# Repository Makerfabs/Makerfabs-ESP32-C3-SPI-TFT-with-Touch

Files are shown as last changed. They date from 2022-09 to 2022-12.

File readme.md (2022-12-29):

# Makerfabs ESP32-C3 SPI TFT with Touch

```c++
/*
Version:		V1.3
Author:			Vincent
Create Date:	2022/9/23
Note:
		2022/10/13	V1.1: Add example
		2022/10/18	V1.2: Add Line Chart demo
		2022/12/29	V1.3: Change wiki link
*/
```
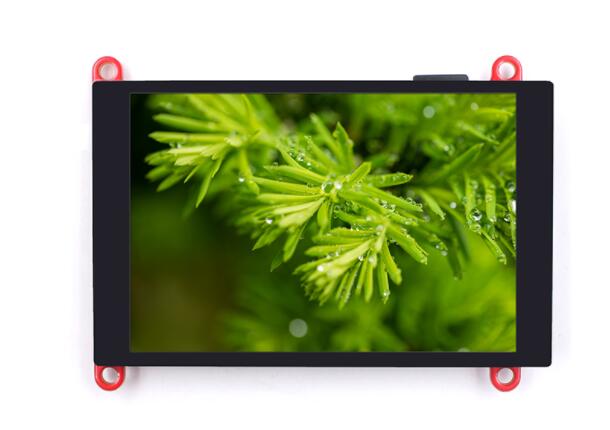
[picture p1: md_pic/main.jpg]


[toc]

# Makerfabs

[Makerfabs home page](https://www.makerfabs.com/)

[Makerfabs Wiki](https://wiki.makerfabs.com/)

# Makerfabs ESP32-C3 SPI TFT with Touch
## Intruduce

Product Link ：[ESP32-C3 SPI TFT with Touch 3.5'' ILI9488](https://www.makerfabs.com/ep32-c3-risc-v-spi-tft-touch.html)

Wiki Link : [ESP32-C3_SPI_TFT_with_Touch](https://wiki.makerfabs.com/ESP32_C3_SPI_3.5_TFT_with_Touch.html)

Makerfabs ESP32-C3 TFT Touch equips with ESP32-C3, which is a single-core Wi-Fi and Bluetooth 5 (LE) microcontroller SoC, built around a 32-bit **RISC-V** chip processor with a four-stage pipeline that operates at up to 160 MHz, with 4MB Flash, 400KB SRAM. 

Being a number of the Makerfabs ESP Display family, this ESP32 C3 SPI 3.5 inch Touch is 320*480, with ILI9488 driver. Same as the other Makerfab's ESP32 displays, there 2 USB connectors, one for USB2UART convertor, and 1 USB native; on-board SD card, and Mabee connector(I2C) which is Seeedstudio Grove compatible, so it fits for applications that need sensor connected.

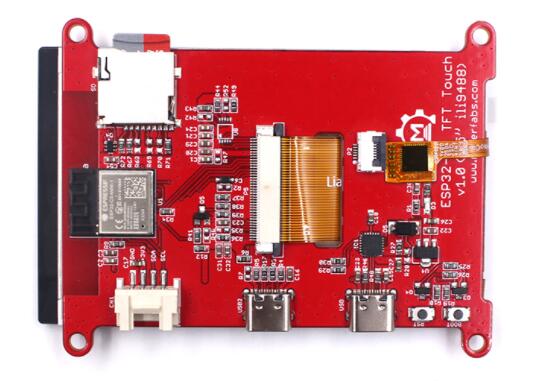
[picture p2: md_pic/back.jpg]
back


## Feature

- Controller: ESP32-C3-MINI-1-N4, 4MB Flash, RISCV-32bit, 160MHz, 400KB SRAM, Bluetooth 5
- Wireless: WiFi & Bluetooth 5.0
- LCD: 3.5inch TFT LCD
- Resolution: 480*320
- Color: RGB
- LCD interface: SPI
- LCD Driver: ili9488
- Touch Panel: Capacitive
- Touch Panel Driver: FT6236
- USB: Dual USB Type-C(one for USB-to-UART and one for native USB)
- USB2UART Chip: CP2104
- Power Supply: USB Type-C 5.0V(4.0V~5.25V)
- Button: Flash button and reset button
- Mabee interface: 1*I2C
- Backlight Controller: Yes
- MicroSD: Yes
- Arduino support: Yes
- Type-C Power Delivery: Not Supported
- Operation temperature: -40℃ to +85℃
- Dimension: 66mm * 84.3mm * 12mm
- Weight: 52g

# Code Explain

## Complier Option

- Install board : ESP32 .
- Install library : LovyanGFX library. 
- Use type-c use cable connect USB-TTL to PC.
- Upload codes, select "ESP32-C3 DEV Module"

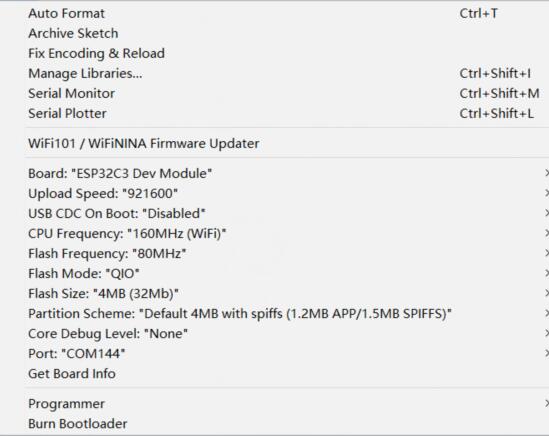
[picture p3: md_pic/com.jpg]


## Firmware

### c3_9488

A simple test procedure. Touch the black area in the middle of the screen, and the screen starts showing solid colors in turn. Finally, an SD card image is displayed.

## Example

### Mabee CO2 Display

SGP30 and SHT31 sensor values are displayed on the screen. Use [Mabee CO2](https://www.makerfabs.com/mabee-tvoc-and-eco2-sgp30-sht31.html) sensor.

Need libraries:

- Adafruit_SGP30
- Adafruit_SHT31

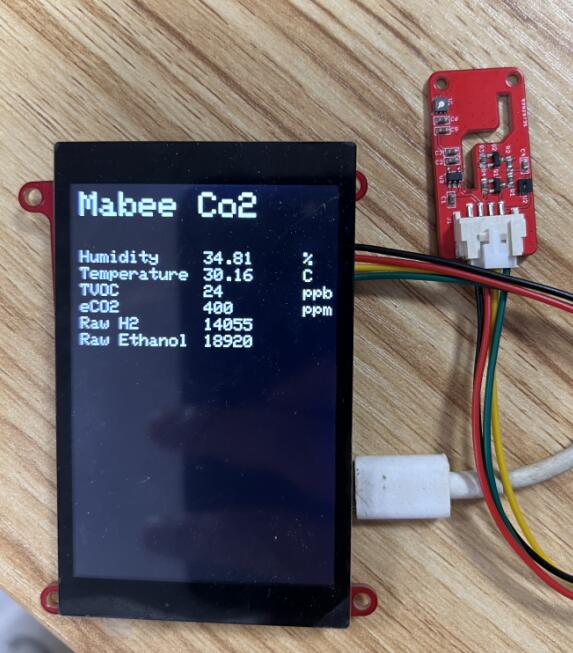
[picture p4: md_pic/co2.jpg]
co2


### TVOC line chart

Shows a line chart of TVOC

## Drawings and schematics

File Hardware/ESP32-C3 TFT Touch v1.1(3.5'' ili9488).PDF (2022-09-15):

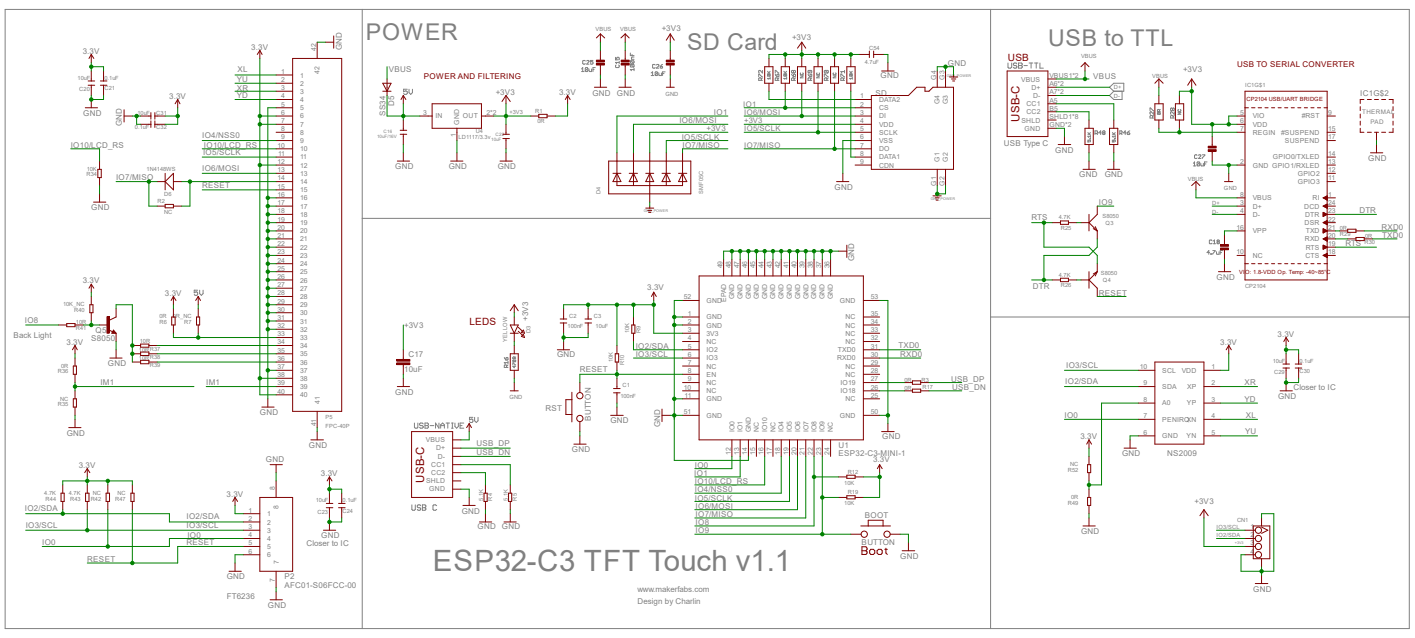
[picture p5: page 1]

USB Type C SD Card

USB TO SERIAL CONVERTER

VIO: 1.8-VDD Op. Temp: -40~85°C USB⁻C USB⁻C

Design by Charlin ESP32-C3 TFT Touch v1.1

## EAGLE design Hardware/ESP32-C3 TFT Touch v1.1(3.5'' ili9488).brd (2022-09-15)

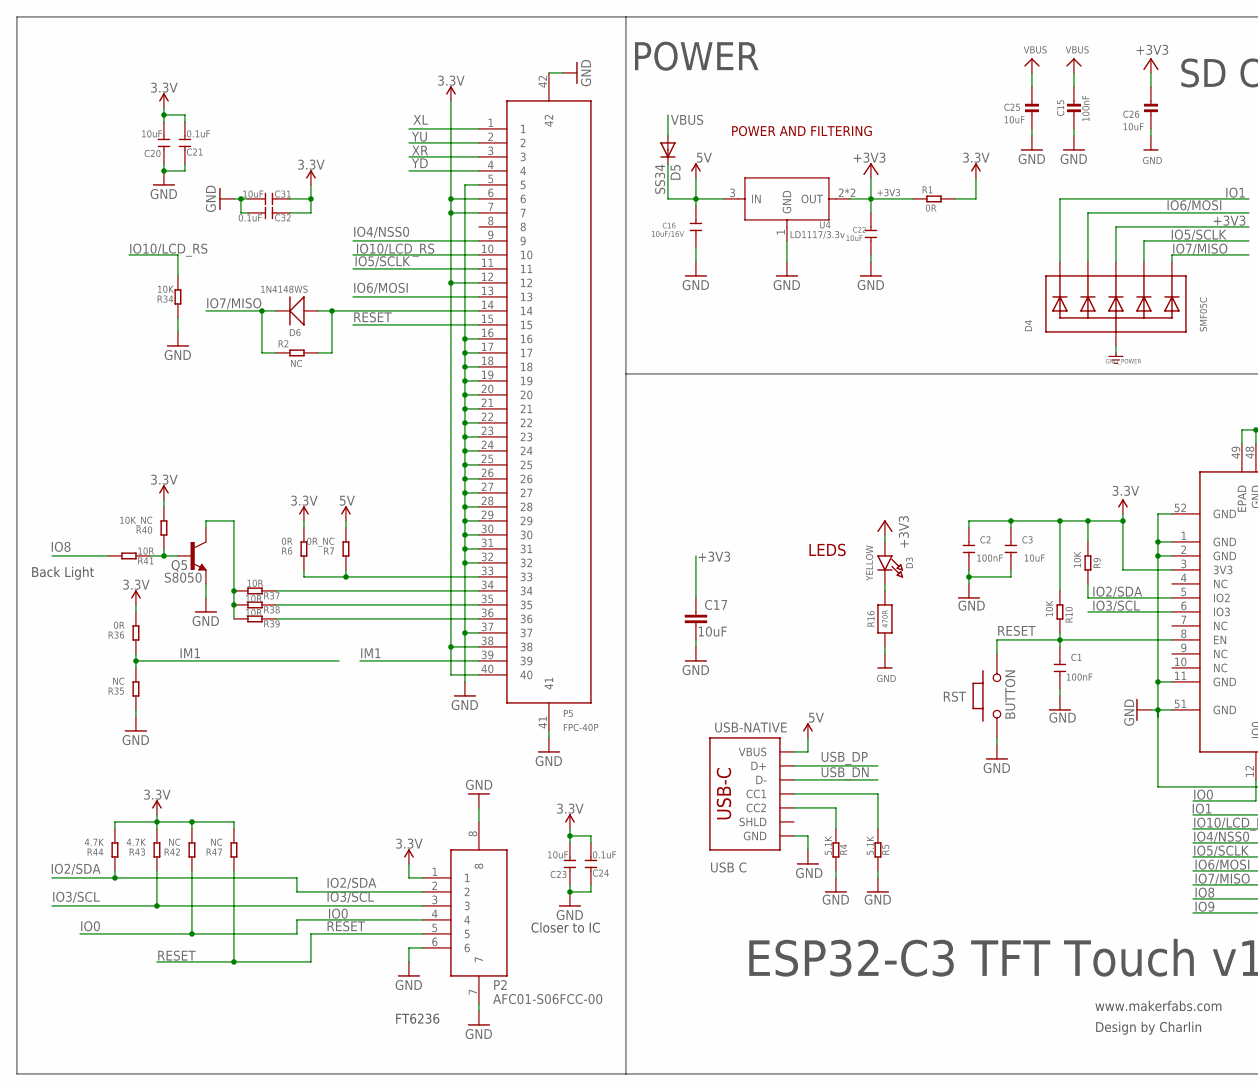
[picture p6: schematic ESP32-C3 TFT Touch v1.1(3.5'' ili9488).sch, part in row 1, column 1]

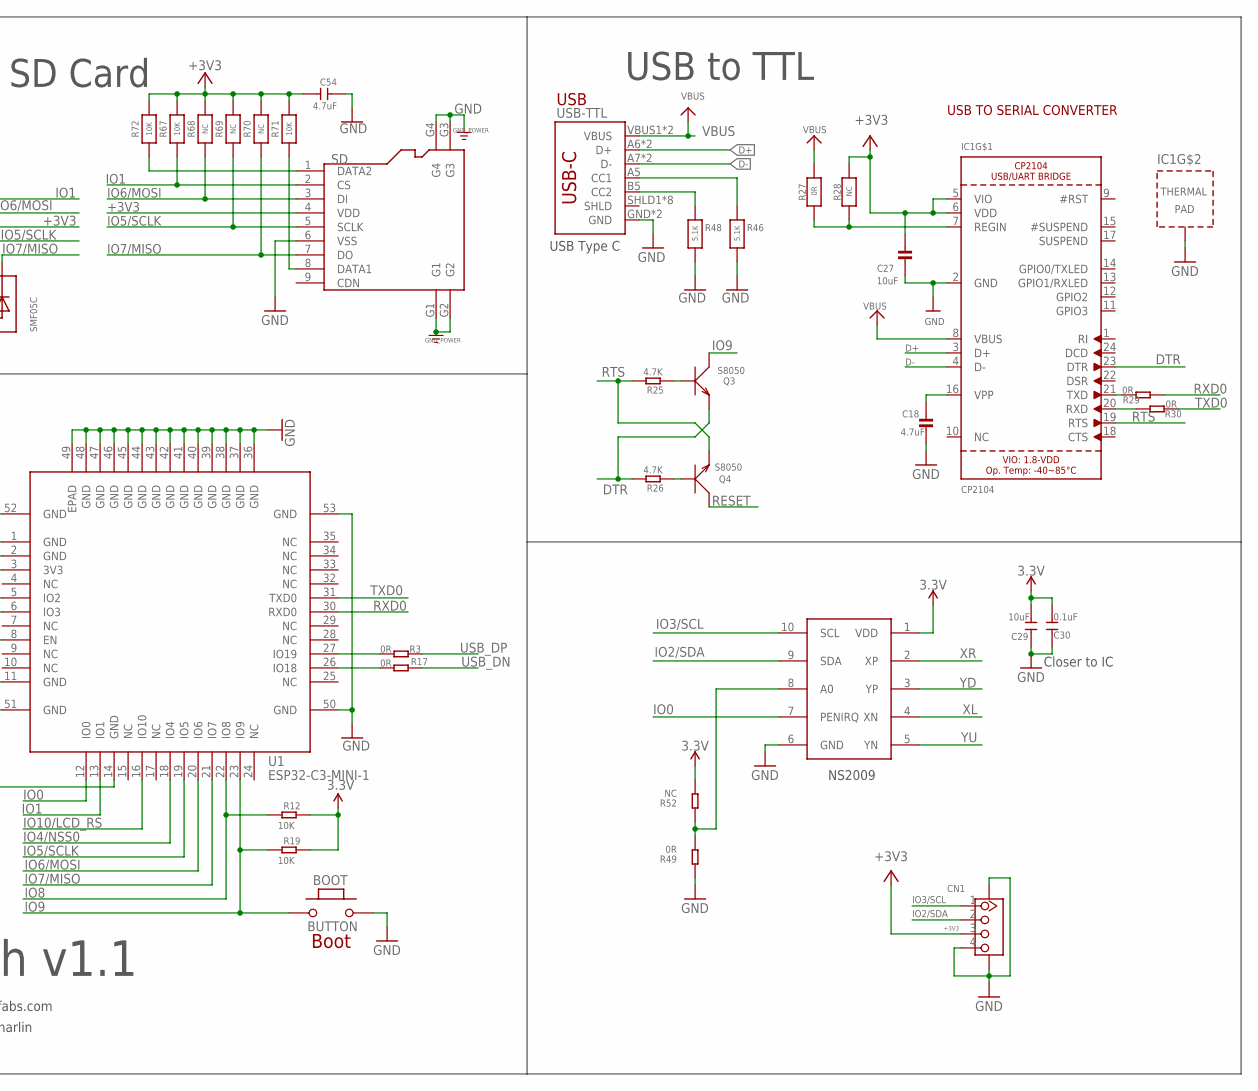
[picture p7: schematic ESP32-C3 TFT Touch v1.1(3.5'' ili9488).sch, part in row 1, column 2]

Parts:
BOOT: BUTTON; 157SW
C1, C2: 100nF; C0603
C3, C17, C22: 10uF; C0603
C15: 100nF; 0603-NO
C16: 10uF/16V; C0603
C18: 4.7uF; 0603-NO
C20, C23, C29, C31: 10uF; DISCRETE_C0603
C21, C24, C30, C32: 0.1uF; DISCRETE_C0603
C25, C26, C27: 10uF; 0603-NO
C54: 4.7uF; DISCRETE_C0603
CN1: GROVE-CONNECTOR-SMD'90D'; HW4-SMD-2.0-90D
D3: YELLOW; CHIPLED_0805_NOOUTLINE
D4: SMF05C; SOT363
D5: SS34; DO-214AC
D6: 1N4148WS; SOD323
IC1: CP2104; QFN24_4MM_SMSC
P2: AFC01-S06FCC-00; SMD8-50P-740L535W
P5: FPC-40P; SMD42-50P-2560L490W
Q3, Q4: S8050; SOT23
Q5: S8050; SPARKFUN_SOT23
R1, R3, R17, R29, R30: 0R; R0603
R2: NC; R0603
R4, R5: 5.1K; R0603
R6, R36, R49: 0R; DISCRETE_R0603
R7: 0R_NC; DISCRETE_R0603
R9, R10, R12, R19: 10K; R0603
R16: 470R; 0603-NO
R25, R26: 4.7K; R0603
R27: 0R; 0603-NO
R28, R68, R69, R70: NC; 0603-NO
R34: 10K; DISCRETE_R0603
R35, R42, R47, R52: NC; DISCRETE_R0603
R37, R38, R39, R41: 10R; DISCRETE_R0603
R40: 10K_NC; DISCRETE_R0603
R43, R44: 4.7K; DISCRETE_R0603
R46, R48: 5.1K; 0603-NO
R67, R71, R72: 10K; 0603-NO
RST: BUTTON; 157SW
SD: HOLDER-MICROSD-9P; 9P-SMD-W/-RING
U1: ESP32-C3-MINI-1
U4: LD1117/3.3v; SOT89
U8: NS2009; MSOP10
USB-NATIVE: USB C; USB-C-16P-4LAYER-ISOLATED
USB-TTL: USB_C5; USB-C-16P-5

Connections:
3.3V: C2.2, C3.2, C20.2, C21.2, C23.2, C24.2, C29.2, C30.2, C31.1, C32.1, P2.1, P5.6, P5.7, P5.12, P5.38, P5.40, R1.2, R6.2, R9.1, R10.1, R12.2, R19.2, R36.2, R40.2, R42.2, R43.2, R44.2, R47.2, R52.2, U1.3 (3V3), U8.1 (VDD)
5V: C16.1, D5.C, R7.2, U4.3 (IN), USB-NATIVE.VBUS1 (VBUS), USB-NATIVE.VBUS2 (VBUS)
+3V3: C17.1, C22.1, C26.1, C27.1, C54.2, CN1.3, D3.A, D4.4 (C3), IC1.5 (VIO), IC1.6 (VDD), R1.1, R28.1, R67.2, R68.2, R69.2, R70.2, R71.2, R72.2, SD.4 (VDD), U4.2 (OUT), U4.4 (OUT)
D+: IC1.3 (D+), USB-TTL.A6 (D+), USB-TTL.B6 (D+)
D-: IC1.4 (D-), USB-TTL.A7 (D-), USB-TTL.B7 (D-)
DTR: IC1.23 (DTR), Q3.2 (E), R26.2
GND: BOOT.2, C1.1, C2.1, C3.1, C15.2, C16.2, C17.2, C18.2, C20.1, C21.1, C22.2, C23.1, C24.1, C25.2, C26.2, C27.2, C29.1, C30.1, C31.2, C32.2, C54.1, CN1.4, CN1.SS1, CN1.SS2, D4.2 (A), IC1.2 (GND), IC1.THERM (TP), P2.6, P2.7, P2.8, P5.5, P5.16, P5.17, P5.18, P5.19, P5.20, P5.21, P5.22, P5.23, P5.24, P5.25, P5.26, P5.27, P5.28, P5.29, P5.30, P5.31, P5.32, P5.37, P5.41, P5.42, Q5.2 (E), R4.1, R5.1, R16.1, R34.1, R35.1, R46.2, R48.2, R49.1, RST.1, SD.6 (VSS), SD.G1, SD.G2, SD.G3, SD.G4, U1.1 (GND), U1.2 (GND), U1.11 (GND), U1.14 (GND), U1.36 (GND), U1.37 (GND), U1.38 (GND), U1.39 (GND), U1.40 (GND), U1.41 (GND), U1.42 (GND), U1.43 (GND), U1.44 (GND), U1.45 (GND), U1.46 (GND), U1.47 (GND), U1.48 (GND), U1.49 (EPAD), U1.50 (GND), U1.51 (GND), U1.52 (GND), U1.53 (GND), U4.1 (GND), U8.6 (GND), USB-NATIVE.GND, USB-NATIVE.GND2 (GND), USB-TTL.GND, USB-TTL.GND2 (GND)
IM1: P5.39, R35.2, R36.1
IO0: P2.4, R42.1, U1.12 (IO0), U8.7 (PENIRQ)
IO1: D4.1 (C1), R67.1, SD.2 (CS), U1.13 (IO1)
IO2/SDA: CN1.2, P2.2, R9.2, R44.1, U1.5 (IO2), U8.9 (SDA)
IO3/SCL: CN1.1, P2.3, R43.1, U1.6 (IO3), U8.10 (SCL)
IO4/NSS0: P5.9, U1.18 (IO4)
IO5/SCLK: D4.5 (C4), P5.11, R69.1, SD.5 (SCLK), U1.19 (IO5)
IO6/MOSI: D4.3 (C2), P5.13, R68.1, SD.3 (DI), U1.20 (IO6)
IO7/MISO: D4.6 (C5), D6.-, R2.1, R70.1, SD.7 (DO), U1.21 (IO7)
IO8: R12.1, R41.2, U1.22 (IO8)
IO9: BOOT.1, Q3.3 (C), R19.1, U1.23 (IO9)
IO10/LCD_RS: P5.10, R34.2, U1.16 (IO10)
unnamed: C18.1, IC1.16 (VPP)
unnamed: Q4.1 (B), R26.1
unnamed: Q3.1 (B), R25.1
unnamed: D6.+, P5.14, R2.2
unnamed: D3.C, R16.2
unnamed: R46.1, USB-TTL.A5 (CC1)
unnamed: R48.1, USB-TTL.B5 (CC2)
unnamed: IC1.7 (REGIN), R27.2, R28.2
unnamed: R3.1, U1.27 (IO19)
unnamed: R5.2, USB-NATIVE.A5 (CC1)
unnamed: R4.2, USB-NATIVE.B5 (CC2)
unnamed: R17.1, U1.26 (IO18)
unnamed: IC1.21 (TXD), R29.2
unnamed: IC1.20 (RXD), R30.2
unnamed: P5.34, R37.1
unnamed: P5.35, R38.1
unnamed: P5.36, R39.1
unnamed: Q5.1 (B), R40.1, R41.1
unnamed: Q5.3 (C), R37.2, R38.2, R39.2
unnamed: R49.2, R52.1, U8.8 (A0)
unnamed: P5.33, R6.1, R7.1
unnamed: R72.1, SD.1 (DATA2)
unnamed: R71.1, SD.8 (DATA1)
RESET: C1.2, P2.5, P5.15, Q4.3 (C), R10.2, R47.1, RST.2, U1.8 (EN)
RTS: IC1.19 (RTS), Q4.2 (E), R25.2
RXD0: R29.1, U1.30 (RXD0)
TXD0: R30.1, U1.31 (TXD0)
USB_DN: R17.2, USB-NATIVE.A7 (D-), USB-NATIVE.B7 (D-)
USB_DP: R3.2, USB-NATIVE.A6 (D+), USB-NATIVE.B6 (D+)
VBUS: C15.1, C25.1, D5.A, IC1.8 (VBUS), R27.1, USB-TTL.VBUS1 (VBUS), USB-TTL.VBUS2 (VBUS)
XL: P5.1, U8.4 (XN)
XR: P5.3, U8.2 (XP)
YD: P5.4, U8.3 (YP)
YU: P5.2, U8.5 (YN)

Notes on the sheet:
www.makerfabs.com
Design by Charlin
USB
LEDS
POWER AND FILTERING
USB TO SERIAL CONVERTER
ESP32-C3 TFT Touch v1.1
POWER
USB to TTL
USB Type C
SD Card
NS2009
FT6236
Closer to IC
Back Light
Boot

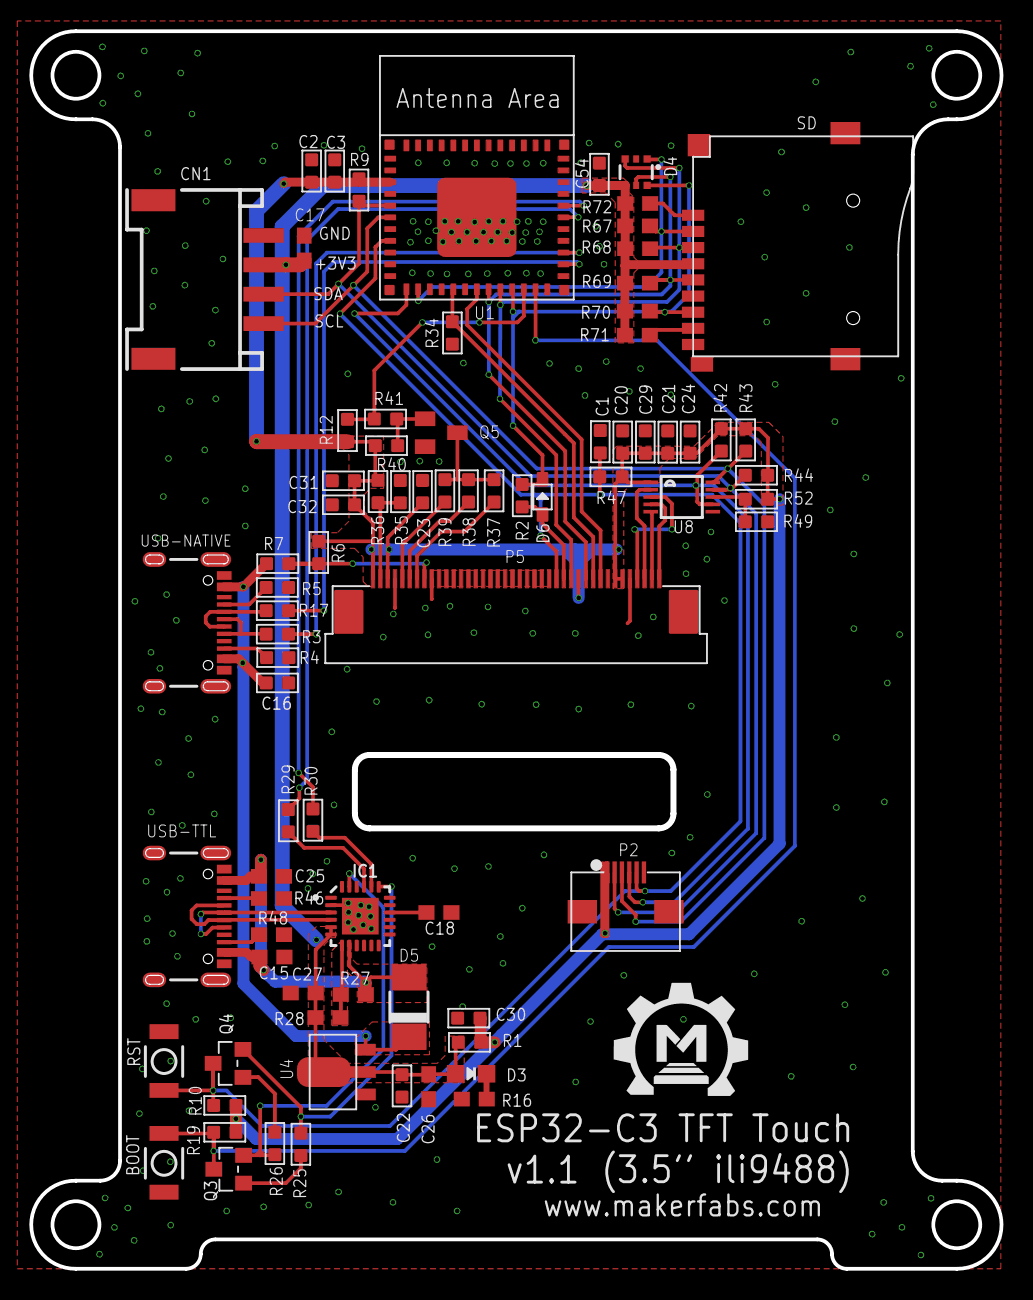
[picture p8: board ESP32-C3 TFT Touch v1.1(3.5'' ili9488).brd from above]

Board: 2 copper layers, 66.1 x 84.3 mm, 81 parts (0 on the bottom side), 53 nets.

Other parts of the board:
U$1: MAKERFABS_0.3

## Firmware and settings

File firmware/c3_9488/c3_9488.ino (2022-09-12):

//测试通过
#define LGFX_USE_V1

#include <LovyanGFX.hpp>
#include <vector>
#include <SPI.h>
#include <SD.h>
#include <FS.h>

#include "FT6236.h"
const int i2c_touch_addr = TOUCH_I2C_ADD;
#define get_pos ft6236_pos

#define LCD_MOSI 6
#define LCD_MISO 7
#define LCD_SCK 5
#define LCD_CS 4
#define LCD_RST -1
#define LCD_DC 10
#define LCD_BL 8

#define I2C_SDA 2
#define I2C_SCL 3

#define SD_CS 1

class LGFX : public lgfx::LGFX_Device
{
    // lgfx::Panel_ILI9341 _panel_instance;
    lgfx::Panel_ILI9488 _panel_instance;
    lgfx::Bus_SPI _bus_instance;

public:
    // コンストラクタを作成し、ここで各種設定を行います。
    // クラス名を変更した場合はコンストラクタも同じ名前を指定してください。
    LGFX(void)
    {
        {                                      // バス制御の設定を行います。
            auto cfg = _bus_instance.config(); // バス設定用の構造体を取得します。

            // SPIバスの設定
            cfg.spi_host = SPI2_HOST;  // 使用するSPIを選択  (VSPI_HOST or HSPI_HOST)
            cfg.spi_mode = 0;          // SPI通信モードを設定 (0 ~ 3)
            cfg.freq_write = 40000000; // 送信時のSPIクロック (最大80MHz, 80MHzを整数で割った値に丸められます)
            cfg.freq_read = 16000000;  // 受信時のSPIクロック
            cfg.spi_3wire = true;      // 受信をMOSIピンで行う場合はtrueを設定
            cfg.use_lock = true;       // トランザクションロックを使用する場合はtrueを設定
            cfg.dma_channel = 1;       // Set the DMA channel (1 or 2. 0=disable)   使用するDMAチャンネルを設定 (0=DMA不使用)
            cfg.pin_sclk = LCD_SCK;    // SPIのSCLKピン番号を設定
            cfg.pin_mosi = LCD_MOSI;   // SPIのMOSIピン番号を設定
            cfg.pin_miso = LCD_MISO;   // SPIのMISOピン番号を設定 (-1 = disable)
            cfg.pin_dc = LCD_DC;       // SPIのD/Cピン番号を設定  (-1 = disable)
                                       // SDカードと共通のSPIバスを使う場合、MISOは省略せず必ず設定してください。

            _bus_instance.config(cfg);              // 設定値をバスに反映します。
            _panel_instance.setBus(&_bus_instance); // バスをパネルにセットします。
        }

        {                                        // 表示パネル制御の設定を行います。
            auto cfg = _panel_instance.config(); // 表示パネル設定用の構造体を取得します。

            cfg.pin_cs = LCD_CS;   // CSが接続されているピン番号   (-1 = disable)
            cfg.pin_rst = LCD_RST; // RSTが接続されているピン番号  (-1 = disable)
            cfg.pin_busy = -1;     // BUSYが接続されているピン番号 (-1 = disable)

            // ※ 以下の設定値はパネル毎に一般的な初期値が設定されていますので、不明な項目はコメントアウトして試してみてください。

            cfg.memory_width = 320;   // ドライバICがサポートしている最大の幅
            cfg.memory_height = 480;  // ドライバICがサポートしている最大の高さ
            cfg.panel_width = 320;    // 実際に表示可能な幅
            cfg.panel_height = 480;   // 実際に表示可能な高さ
            cfg.offset_x = 0;         // パネルのX方向オフセット量
            cfg.offset_y = 0;         // パネルのY方向オフセット量
            cfg.offset_rotation = 0;  // 回転方向の値のオフセット 0~7 (4~7は上下反転)
            cfg.dummy_read_pixel = 8; // ピクセル読出し前のダミーリードのビット数
            cfg.dummy_read_bits = 1;  // ピクセル以外のデータ読出し前のダミーリードのビット数
            cfg.readable = true;      // データ読出しが可能な場合 trueに設定
            cfg.invert = false;       // パネルの明暗が反転してしまう場合 trueに設定
            cfg.rgb_order = false;    // パネルの赤と青が入れ替わってしまう場合 trueに設定
            cfg.dlen_16bit = false;   // データ長を16bit単位で送信するパネルの場合 trueに設定
            cfg.bus_shared = true;    // SDカードとバスを共有している場合 trueに設定(drawJpgFile等でバス制御を行います)

            _panel_instance.config(cfg);
        }

        setPanel(&_panel_instance); // 使用するパネルをセットします。
    }
};

LGFX lcd;

void setup(void)
{
    Serial.begin(115200);

    lcd.init();
    lcd.fillScreen(TFT_WHITE);

    lcd.setTextSize(3);

    sd_init();
    touch_init();

    lcd.fillRect(80, 160, 160, 160, TFT_BLACK);
    lcd.setCursor(90, 180);
    lcd.println(" TOUCH");
    lcd.setCursor(90, 210);
    lcd.println("  TO");
    lcd.setCursor(90, 240);
    lcd.println("CONTINUE");

    int pos[2] = {0, 0};

    while (1)
    {
        get_pos(pos);

        if (pos[0] > 80 && pos[0] < 240 && pos[1] > 160 && pos[1] < 320)
            break;
        delay(100);
    }
}

static int colors[] = {TFT_RED, TFT_GREEN, TFT_BLUE, TFT_YELLOW};

int i = 0;

void loop(void)
{
    lcd.fillScreen(colors[i++]);
    delay(1000);

    if (i > 3)
    {
        i = 0;
        lcd.setRotation(3);
        print_img(SD, "/logo.bmp", 480, 320);
        delay(1000);
    }
}

void touch_init()
{
    // I2C init
    Wire.begin(I2C_SDA, I2C_SCL);
    byte error, address;

    Wire.beginTransmission(i2c_touch_addr);
    error = Wire.endTransmission();

    if (error == 0)
    {
        Serial.print("I2C device found at address 0x");
        Serial.print(i2c_touch_addr, HEX);
        Serial.println("  !");
    }
    else if (error == 4)
    {
        Serial.print("Unknown error at address 0x");
        Serial.println(i2c_touch_addr, HEX);
        lcd.setCursor(10, 40);
        lcd.println("Touch Failed");
    }
}

void sd_init()
{
    // SD_SPI.begin(SD_SCK, SD_MISO, SD_MOSI);
    if (!SD.begin(SD_CS, SPI, 40000000))
    {
        Serial.println("Card Mount Failed");
        lcd.setCursor(10, 10);
        lcd.println("SD Card Failed");
        while (1)
            delay(1000);
    }
    else
    {
        Serial.println("Card Mount Successed");
    }

    Serial.println("SD init over.");
}

// Display image from file
int print_img(fs::FS &fs, String filename, int x, int y)
{

    File f = fs.open(filename, "r");
    if (!f)
    {
        Serial.println("Failed to open file for reading");
        f.close();
        return 0;
    }

    f.seek(54);
    int X = x;
    int Y = y;
    uint8_t RGB[3 * X];
    for (int row = 0; row < Y; row++)
    {
        f.seek(54 + 3 * X * row);
        f.read(RGB, 3 * X);

        lcd.pushImage(0, row, X, 1, (lgfx::rgb888_t *)RGB);
    }

    f.close();
    return 0;
}

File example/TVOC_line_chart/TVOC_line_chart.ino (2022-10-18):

#include <SPI.h>
#include <Wire.h>
#include "Adafruit_SGP30.h"
#include "Adafruit_SHT31.h"
#include "C3_SPI_9488.h"

#define I2C_SDA_PIN 2
#define I2C_SCL_PIN 3

Adafruit_SHT31 sht31 = Adafruit_SHT31();
Adafruit_SGP30 sgp;
LGFX lcd;

int list_1[50] = {0};
int list_1_length = 20;
int list_2[50] = {0};
int list_2_length = 20;
int interval = 2000;

void setup(void)
{
    Serial.begin(115200);

    tft_init();
    sensor_init();

    draw_line_chart_window("TVOC Line Chart ( Unit : ppb ) ", (String) "Interval : " + interval + " ms", list_1_length, 0, 1200, TFT_WHITE);
    draw_line_chart_window2("ECO2 Line Chart ( Unit : ppm ) ", (String) "Interval : " + interval + " ms", list_2_length, 0, 5000, TFT_WHITE);
    delay(2000);
}

void loop()
{
    draw_line_chart(list_1, list_1_length, 0, 1200, TFT_WHITE);
    draw_line_chart2(list_2, list_2_length, 0, 5000, TFT_WHITE);
    delay(interval);

    int tvoc = 0;
    int eco2 = 0;
    sensor_read(&tvoc, &eco2);

    draw_line_chart(list_1, list_1_length, 0, 1200, TFT_BLACK);
    draw_line_chart2(list_2, list_2_length, 0, 5000, TFT_BLACK);
    add_list(list_1, list_1_length, tvoc);
    add_list(list_2, list_2_length, eco2);
}

// Sensor
uint32_t getAbsoluteHumidity(float temperature, float humidity)
{
    // approximation formula from Sensirion SGP30 Driver Integration chapter 3.15
    const float absoluteHumidity = 216.7f * ((humidity / 100.0f) * 6.112f * exp((17.62f * temperature) / (243.12f + temperature)) / (273.15f + temperature)); // [g/m^3]
    const uint32_t absoluteHumidityScaled = static_cast<uint32_t>(1000.0f * absoluteHumidity);                                                                // [mg/m^3]
    return absoluteHumidityScaled;
}

void sensor_init()
{
    Serial.println("Check Sensor");

    Wire.begin(I2C_SDA_PIN, I2C_SCL_PIN);
    Wire.setClock(100000UL);

    if (!sht31.begin(0x44))
    {
        Serial.println("SHT31 not found.");
    }
    delay(100);

    if (!sgp.begin())
    {
        Serial.println("SGP30 not found.");
    }
}

void sensor_read(int *tvoc, int *eco2)
{

    float humidity = sht31.readHumidity();
    float temperature = sht31.readTemperature();

    Serial.print("humidity=");
    Serial.println(humidity);
    Serial.print("temperature=");
    Serial.println(temperature);

    sgp.setHumidity(getAbsoluteHumidity(temperature, humidity));

    if (!sgp.IAQmeasure())
    {
        Serial.println("Measurement failed");
        return;
    }
    Serial.print("TVOC ");
    Serial.print(*tvoc = sgp.TVOC);
    Serial.print(" ppb\t");
    Serial.print("eCO2 ");
    Serial.print(*eco2 = sgp.eCO2);
    Serial.println(" ppm");
}
// TFT

void tft_init()
{
    lcd.init();
    lcd.fillScreen(TFT_BLACK);

    lcd.setTextSize(2);
    lcd.setTextColor(TFT_WHITE);

    // lcd.fillRect(80, 160, 160, 160, TFT_BLACK);
    // lcd.setCursor(10, 10);
    // lcd.println("Mabee Co2");
    // lcd.setTextSize(2);
}

void draw_line_chart_window(String text1, String text2, int length, int low, int high, int color)
{
    // draw rect and unit
    // lcd.drawRect(20, 20, 280, 200, color);
    lcd.drawLine(30, 20, 30, 220, color);
    lcd.drawLine(30, 220, 300, 220, color);

    lcd.drawLine(20, 20, 30, 20, color);
    lcd.drawLine(20, 120, 30, 120, color);

    lcd.setTextColor(color);
    lcd.setTextSize(1);

    lcd.setCursor(0, 10);
    lcd.println(high);

    lcd.setCursor(80, 10);
    lcd.println(text1);

    lcd.setCursor(0, 110);
    lcd.println((high + low) / 2);

    lcd.setCursor(0, 210);
    lcd.println(low);

    lcd.setCursor(80, 230);
    lcd.println(text2);

    int x_start = 32;
    int x_unit = 280 / (length - 1);
    for (int i = 0; i < length; i++)
    {
        int x = x_start + x_unit * i;
        if (i != 0 && i != length - 1)
            lcd.drawLine(x, 220, x, 225, color);
    }
}

void draw_line_chart(int *list, int length, int low, int high, int color)
{
    // list to position
    int pos[50][2] = {0};
    int detail = 50;
    int x_start = 32;
    int y_start = 218;
    int x_unit = 280 / (length - 1);
    int y_unit = -200 / (detail - 1);
    for (int i = 0; i < length; i++)
    {
        pos[i][0] = x_start + i * x_unit;
        int y = map(*(list + i), low, high, 0, detail);
        if (y > detail)
            y = detail;
        pos[i][1] = y_start + y_unit * y;
    }

    // draw line chart
    for (int i = 0; i < length - 1; i++)
    {
        lcd.drawLine(pos[i][0], pos[i][1], pos[i + 1][0], pos[i + 1][1], color);
    }
}

void draw_line_chart_window2(String text1, String text2, int length, int low, int high, int color)
{
    // draw rect and unit
    // lcd.drawRect(20, 20, 280, 200, color);
    lcd.drawLine(30, 260, 30, 460, color);
    lcd.drawLine(30, 460, 300, 460, color);

    lcd.drawLine(20, 260, 30, 260, color);
    lcd.drawLine(20, 360, 30, 360, color);

    lcd.setTextColor(color);
    lcd.setTextSize(1);

    lcd.setCursor(0, 250);
    lcd.println(high);

    lcd.setCursor(80, 250);
    lcd.println(text1);

    lcd.setCursor(0, 350);
    lcd.println((high + low) / 2);

    lcd.setCursor(0, 450);
    lcd.println(low);

    lcd.setCursor(80, 470);
    lcd.println(text2);

    int x_start = 32;
    int x_unit = 280 / (length - 1);
    for (int i = 0; i < length; i++)
    {
        int x = x_start + x_unit * i;
        if (i != 0 && i != length - 1)
            lcd.drawLine(x, 460, x, 465, color);
    }
}

void draw_line_chart2(int *list, int length, int low, int high, int color)
{
    // list to position
    int pos[50][2] = {0};
    int detail = 50;
    int x_start = 32;
    int y_start = 458;
    int x_unit = 280 / (length - 1);
    int y_unit = -200 / (detail - 1);
    for (int i = 0; i < length; i++)
    {
        pos[i][0] = x_start + i * x_unit;
        int y = map(*(list + i), low, high, 0, detail);
        if (y > detail)
            y = detail;
        pos[i][1] = y_start + y_unit * y;
    }

    // draw line chart
    for (int i = 0; i < length - 1; i++)
    {
        lcd.drawLine(pos[i][0], pos[i][1], pos[i + 1][0], pos[i + 1][1], color);
    }
}

// Data
void add_list(int *list, int length, int num)
{
    for (int i = length - 2; i >= 0; i--)
    {
        *(list + i + 1) = *(list + i);
    }
    *list = num;
}

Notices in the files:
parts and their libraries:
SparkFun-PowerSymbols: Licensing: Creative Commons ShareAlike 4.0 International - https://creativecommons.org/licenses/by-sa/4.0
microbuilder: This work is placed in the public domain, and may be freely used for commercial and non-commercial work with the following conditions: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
